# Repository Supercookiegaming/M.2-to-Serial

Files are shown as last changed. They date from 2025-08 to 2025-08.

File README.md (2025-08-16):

# M.2-to-Serial


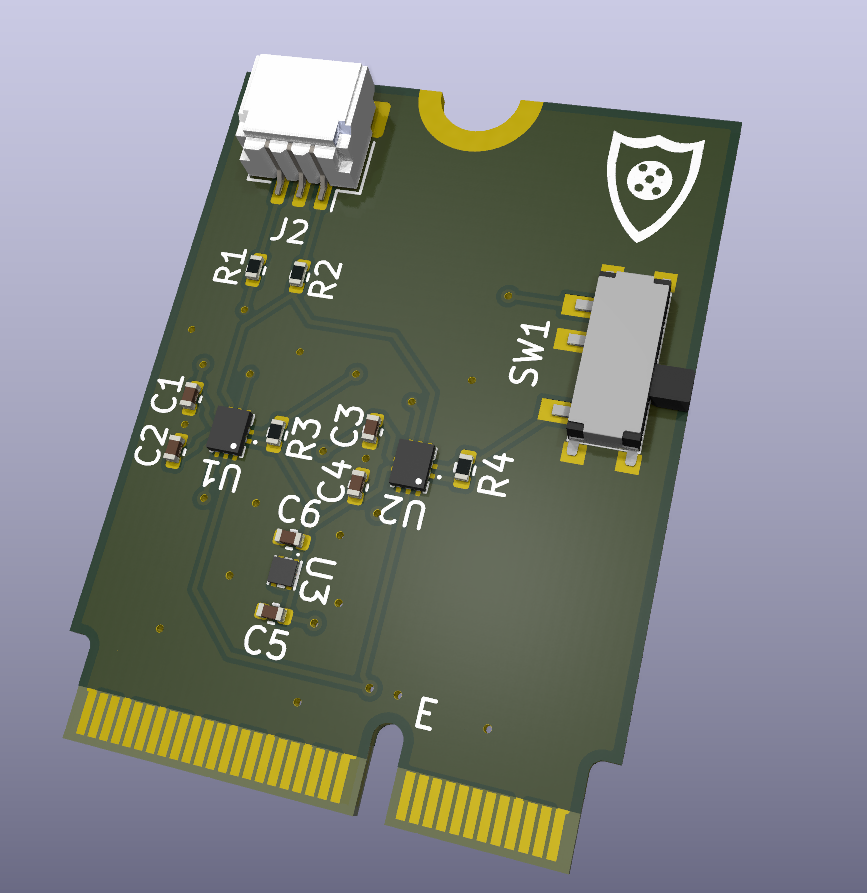
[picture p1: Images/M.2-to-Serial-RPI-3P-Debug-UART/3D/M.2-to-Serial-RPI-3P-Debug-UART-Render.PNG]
RPI UART


## Overview
The goals of this project is to utilize the UART lines on E key M.2 conbnectors to make serial ports. There are plans to have multiple types of serial ports. Currently the [RPI UART standard](https://datasheets.raspberrypi.com/debug/debug-connector-specification.pdf) has been mostly implemented and an RS-232 header is currently being developed. If you have a specific connector you want please make a feature request in the issues section.

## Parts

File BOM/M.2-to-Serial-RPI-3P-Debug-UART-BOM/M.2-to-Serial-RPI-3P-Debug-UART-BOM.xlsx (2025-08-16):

Board QTY | 1
Total Price | 3.79
Board Designator | Part Number | Part Purpose | QTY per Board | Unit Price | QTY Needed | Total Price | Link
U1, U2 | SN74AXC2T245RSWR | Level Shifter | 2 | 0.92 | 2 | 1.84 | https://www.digikey.com/en/products/detail/texas-instruments/SN74AXC2T245RSWR/12642205
U3 | TLV74018PDQNR | 1.8V Regulator | 1 | 0.1 | 1 | 0.1 | https://www.digikey.com/en/products/detail/texas-instruments/TLV74018PDQNR/15857001
J2 | SM03B-SRSS-TB | UART Connector | 1 | 0.44 | 1 | 0.44 | https://www.digikey.com/en/products/detail/jst-sales-america-inc/sm03b-srss-tb/926709
SW1 | SLW-66527511-SMT-TR | Mode Select Switch | 1 | 0.53 | 1 | 0.53 | https://www.digikey.com/en/products/detail/same-sky-formerly-cui-devices/SLW-66527511-SMT-TR/21259964
C1, C2, C3, C4 | 04026D104KAT4A | 0.1uF Decouple Caps | 4 | 0.08 | 4 | 0.32 | https://www.digikey.com/en/products/detail/kyocera-avx/04026D104KAT4A/8107673
C5, C6 | C0402C105K9PACTU | 1uF Decouple Caps | 2 | 0.08 | 2 | 0.16 | https://www.digikey.com/en/products/detail/kemet/C0402C105K9PACTU/1090778
R1, R2 | RC0402FR-07100RL | 100Ω UART Termination Resistors | 2 | 0.10 | 2 | 0.2 | https://www.digikey.com/en/products/detail/yageo/RC0402FR-07100RL/726527
R3, R4 | RC0402JR-0710KL | 10kΩ Pull Up Resistors | 2 | 0.10 | 2 | 0.2 | https://www.digikey.com/en/products/detail/yageo/RC0402JR-0710KL/726418

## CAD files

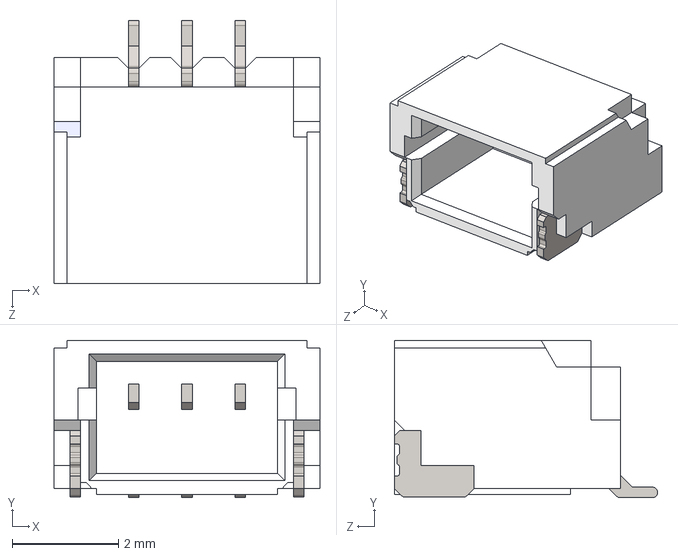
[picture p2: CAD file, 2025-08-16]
KiCad/M.2-to-Serial-KiCad-Library/M.2-to-Serial-3D-Library/SM03B-SRSS-TB_LF__SN_.stp
5.00 x 2.96 x 4.95 mm

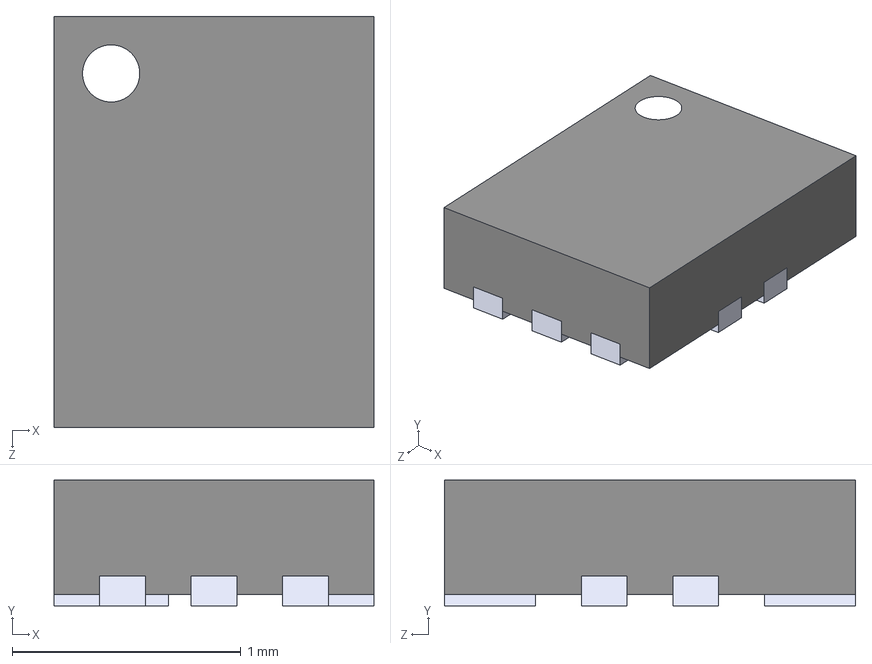
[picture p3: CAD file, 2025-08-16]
KiCad/M.2-to-Serial-KiCad-Library/M.2-to-Serial-3D-Library/SN74AXC2T245RSWR.step
1.40 x 0.55 x 1.80 mm

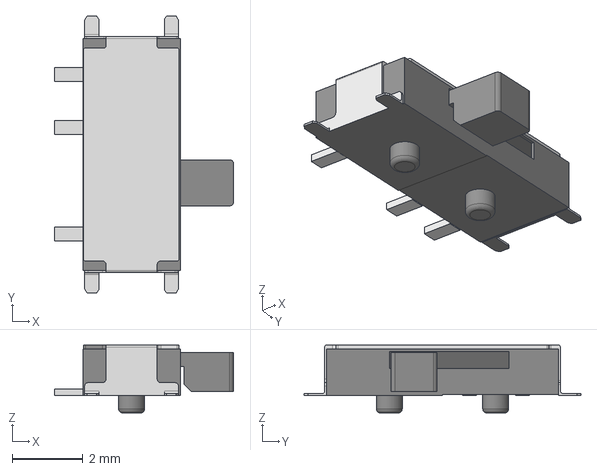
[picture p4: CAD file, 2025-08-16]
KiCad/M.2-to-Serial-KiCad-Library/M.2-to-Serial-3D-Library/SLW-66527511-SMT-TR.stp
5.05 x 7.81 x 1.92 mm

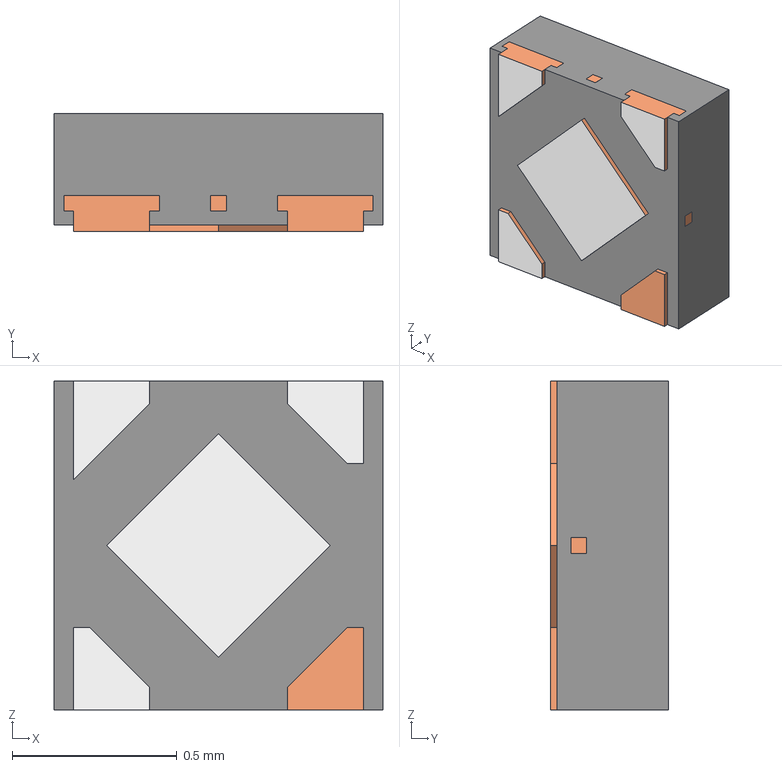
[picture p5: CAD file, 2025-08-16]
KiCad/M.2-to-Serial-KiCad-Library/M.2-to-Serial-3D-Library/TLV74018PDQNR.stp
1.00 x 0.36 x 1.00 mm
MOLD-SNB04A
FRAME-SNB04A

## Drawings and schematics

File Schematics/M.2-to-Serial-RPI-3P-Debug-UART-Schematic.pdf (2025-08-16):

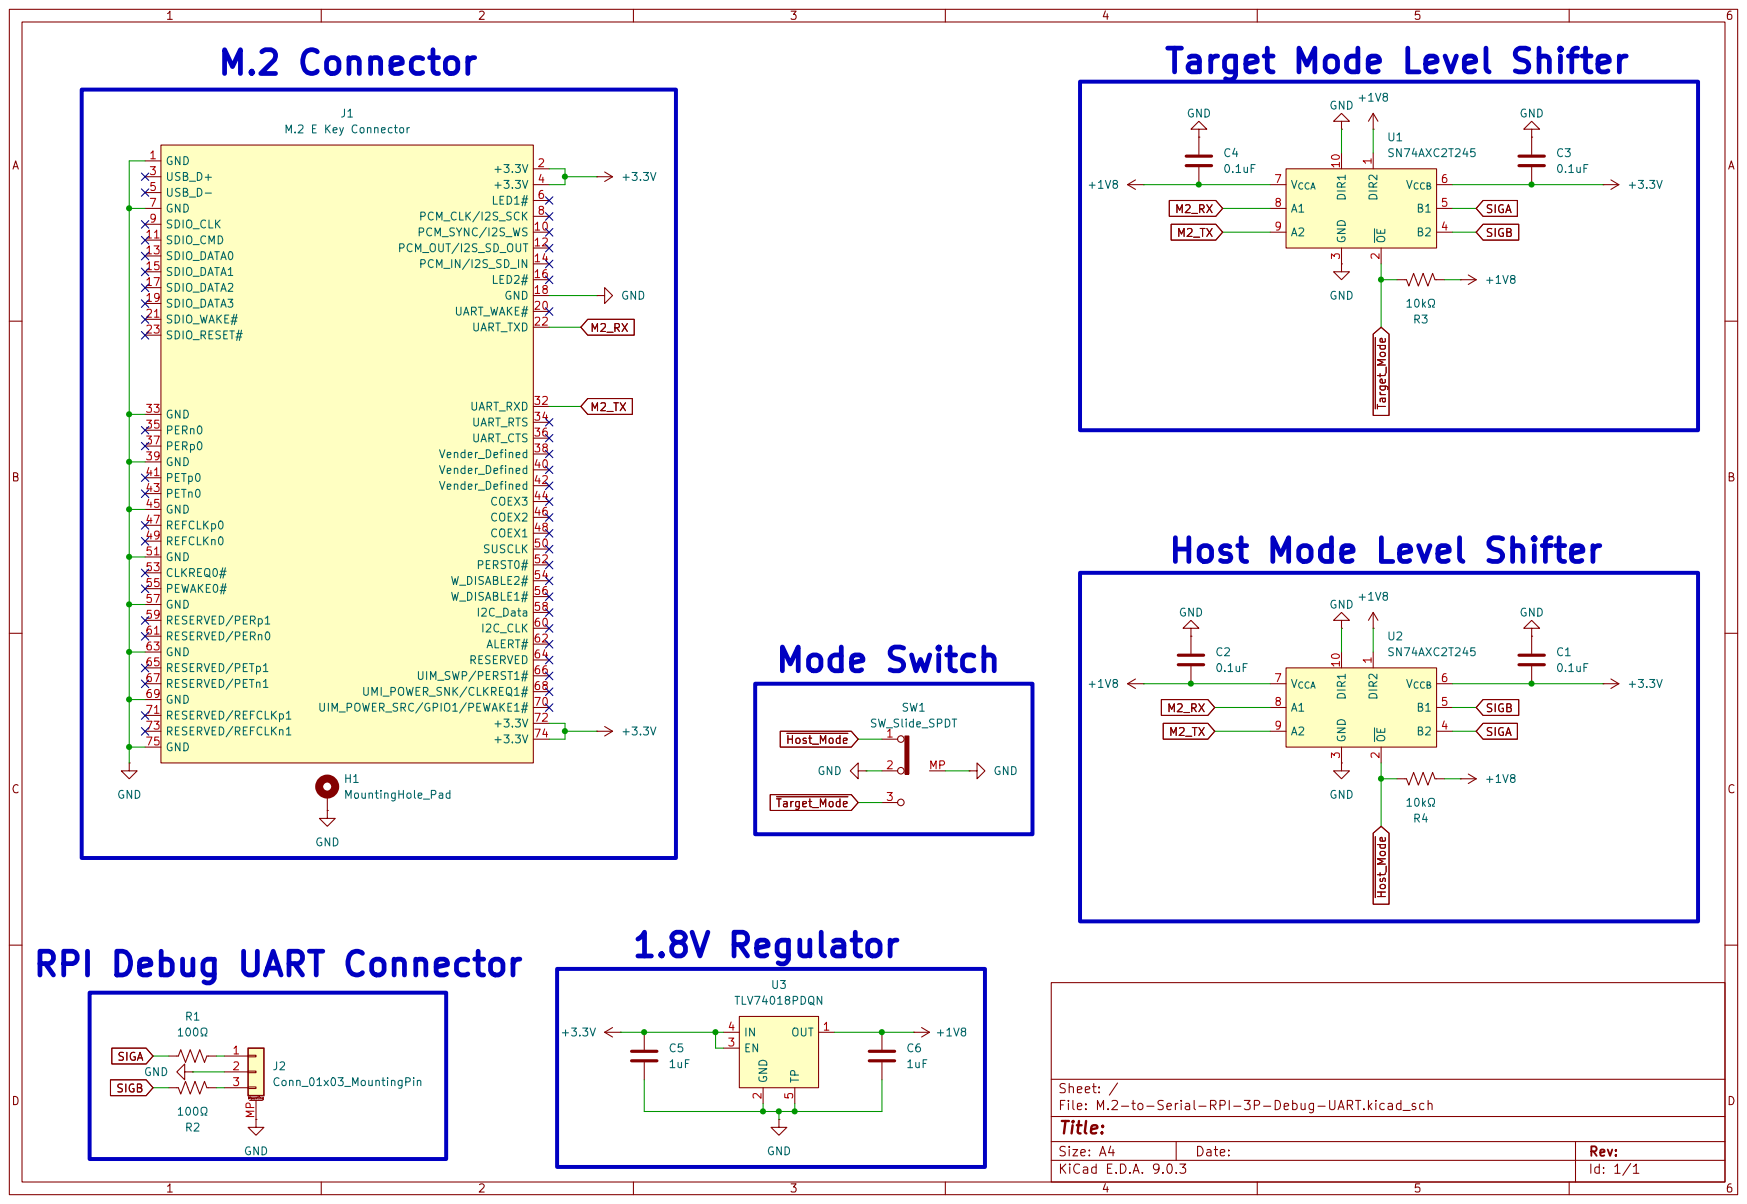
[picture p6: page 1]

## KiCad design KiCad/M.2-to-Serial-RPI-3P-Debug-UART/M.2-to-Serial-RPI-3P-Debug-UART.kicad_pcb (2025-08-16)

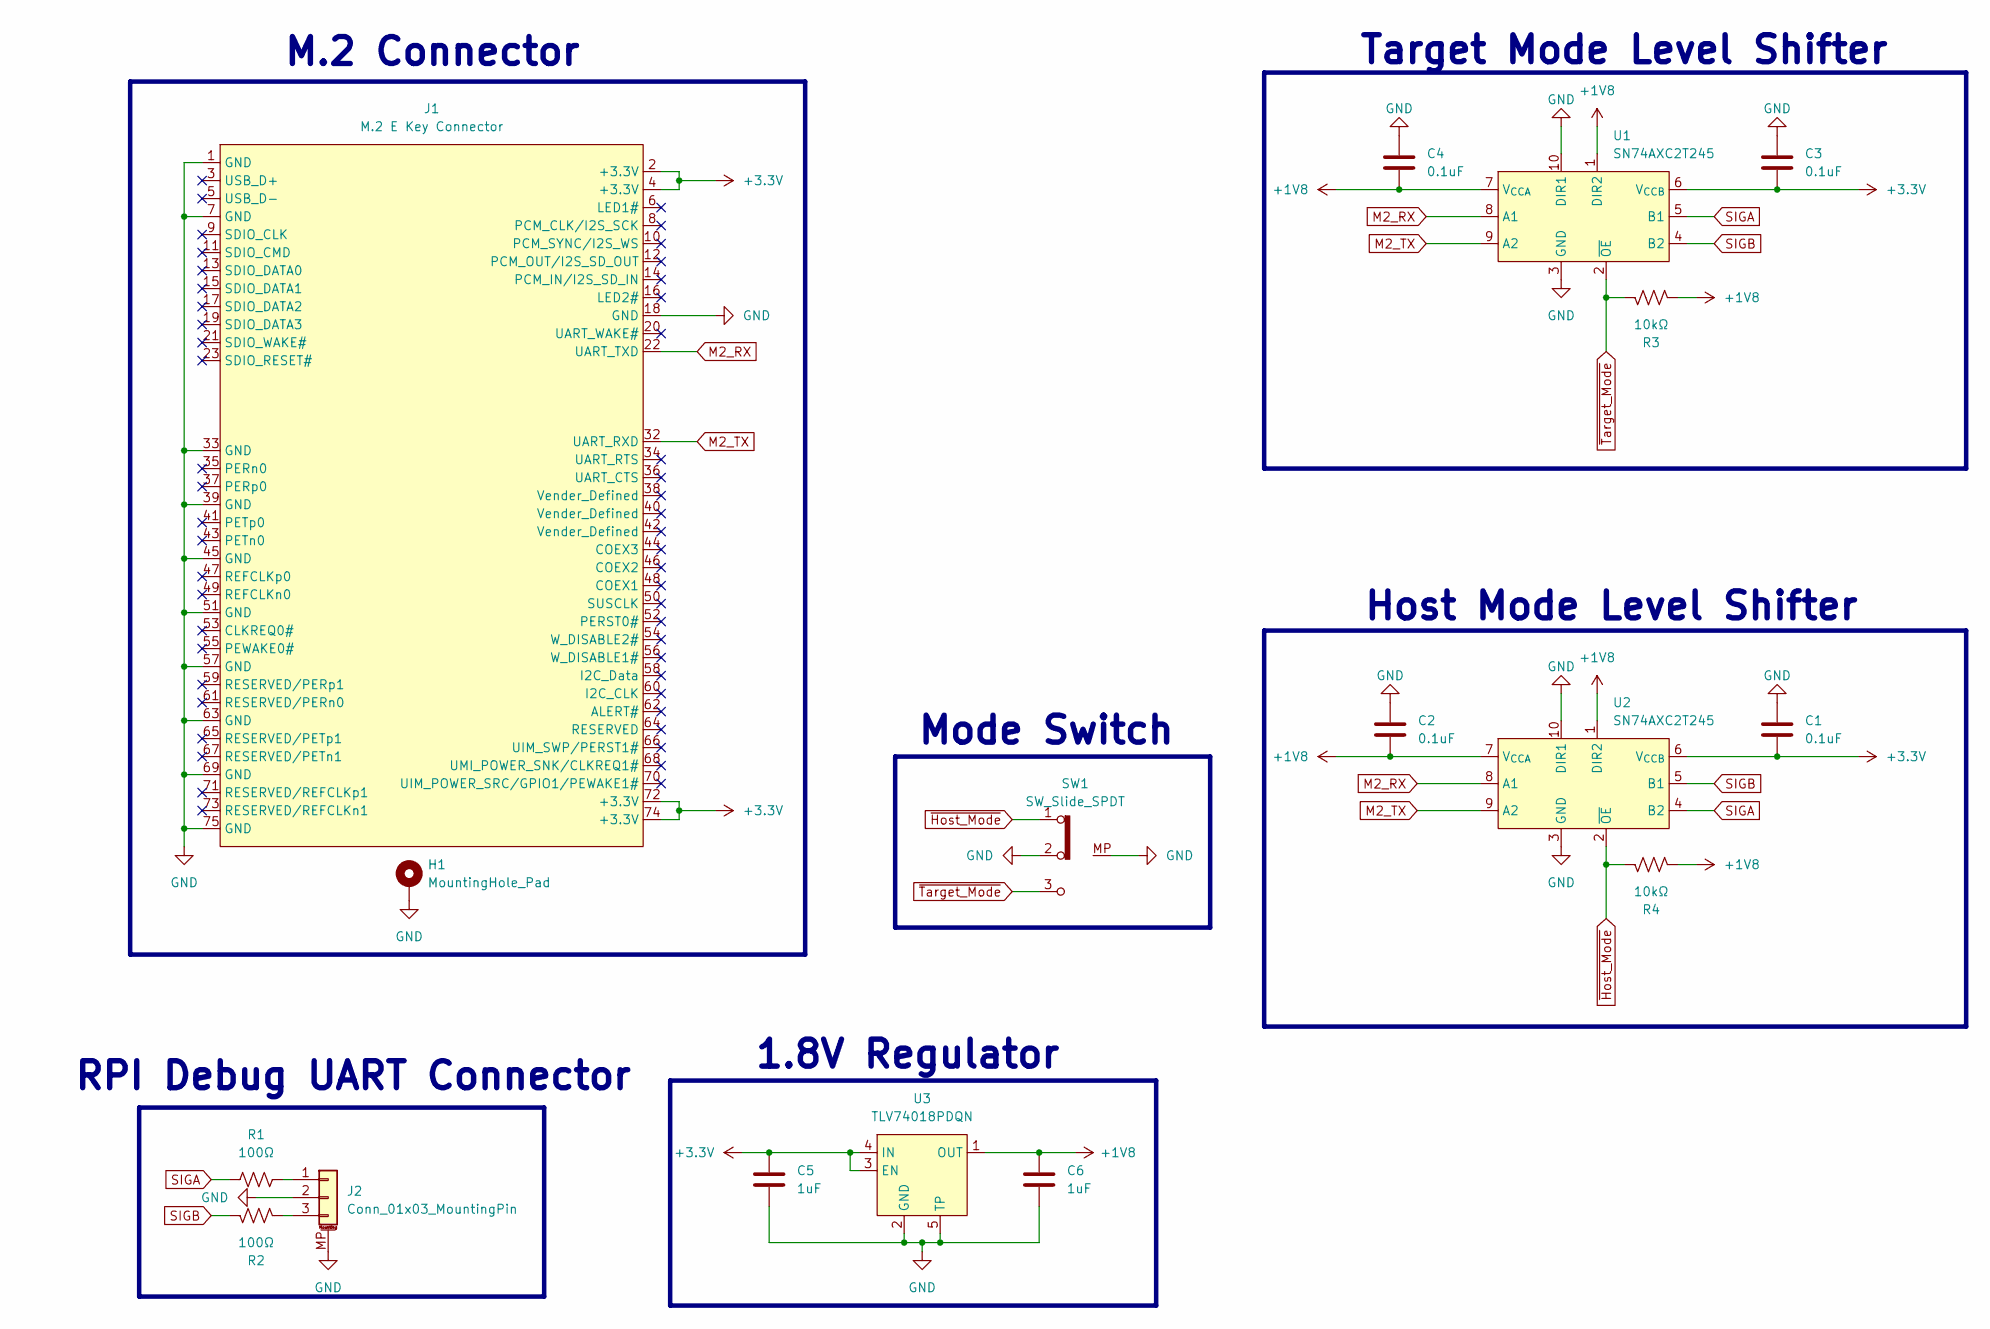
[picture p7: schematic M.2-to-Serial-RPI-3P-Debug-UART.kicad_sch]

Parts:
C1, C2, C3, C4: 0.1uF; C_0402_1005Metric
C5, C6: 1uF; C_0402_1005Metric
H1: MountingHole_Pad; M.2 Mounting Pad
J1: M.2 E Key Connector
J2: Conn_01x03_MountingPin; JST_SH_SM03B-SRSS-TB_1x03-1MP_P1.00mm_Horizontal
R1, R2: 100Ω; R_0402_1005Metric
R3, R4: 10kΩ; R_0402_1005Metric
SW1: SW_Slide_SPDT; SLW-66527511-SMT-TR
U1, U2: SN74AXC2T245
U3: TLV74018PDQN

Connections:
+1V8: C2.2, C4.2, C6.1, R3.1, R4.1, U1.1 (DIR2), U1.7 (V_{CCA}), U2.1 (DIR2), U2.7 (V_{CCA}), U3.1 (OUT)
+3.3V: C1.2, C3.2, C5.1, J1.2 (+3.3V), J1.4 (+3.3V), J1.72 (+3.3V), J1.74 (+3.3V), U1.6 (V_{CCB}), U2.6 (V_{CCB}), U3.3 (EN), U3.4 (IN)
GND: C1.1, C2.1, C3.1, C4.1, C5.2, C6.2, H1.1, J1.1 (GND), J1.7 (GND), J1.18 (GND), J1.33 (GND), J1.39 (GND), J1.45 (GND), J1.51 (GND), J1.57 (GND), J1.63 (GND), J1.69 (GND), J1.75 (GND), J2.2, J2.MP (MountPin), SW1.2 (B), SW1.MP, U1.3 (GND), U1.10 (DIR1), U2.3 (GND), U2.10 (DIR1), U3.2 (GND), U3.5 (TP)
M2_RX: J1.22 (UART_TXD), U1.8 (A1), U2.8 (A1)
M2_TX: J1.32 (UART_RXD), U1.9 (A2), U2.9 (A2)
unnamed: J2.1, R1.2
unnamed: J2.3, R2.1
SIGA: R1.1, U1.5 (B1), U2.4 (B2)
SIGB: R2.2, U1.4 (B2), U2.5 (B1)
~Host_Mode: R4.2, SW1.1 (A), U2.2 (~OE)
~Target_Mode: R3.2, SW1.3 (C), U1.2 (~OE)

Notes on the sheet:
Target Mode Level Shifter
M.2 Connector
1.8V Regulator
Mode Switch
Host Mode Level Shifter
RPI Debug UART Connector

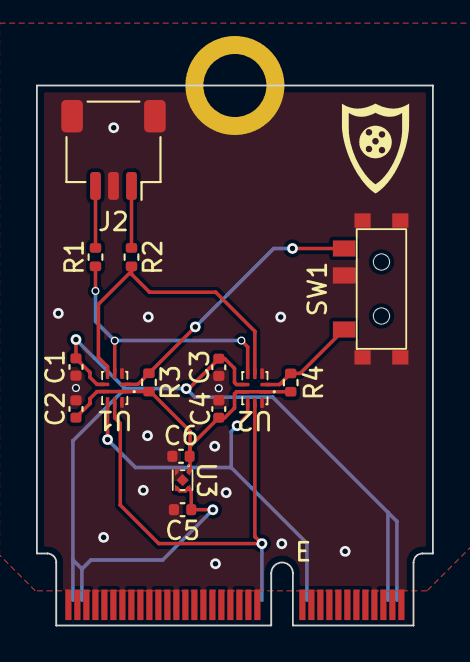
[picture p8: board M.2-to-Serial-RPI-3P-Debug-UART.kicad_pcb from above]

Board: 2 copper layers, 22.0 x 30.0 mm, 17 parts (0 on the bottom side), 11 nets.
